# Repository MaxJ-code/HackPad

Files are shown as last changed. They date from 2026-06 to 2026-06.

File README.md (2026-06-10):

# PhotoPad
PhotoPad is a 12 key macropad with a rotary encoder and an OLED Display, designed to be the best helping hand possible for photography and every other daily-life computer based task.

It's supposed to help speeding up the Lightroom Classic workflow, aswell as basic navigation.
The firmware isn't final, because I don't know the keylayout that fits me best, yet.

# Design
MacropadDesign

# Schematic
Schematic

# PCB
PCB

# Case
It features two separate parts with a support for the screen, the cutout for the USB-C and standoffs for the PCB.

Case_sideview
Case_backview

# Firmware
The firmware is KMK based and easy to understand.

# BOM
- 1x Case (2 3D-printed parts)
- 1x XIAO RP2040
- 11x Cherry MX Switches
- 1x EC11 Rotary Encoder
- 1x 0.91" 128x32 OLED Display
- 12x 1N4148 DO-35 Diodes.
- 4x M3x5x4 Heatset inserts
- 4X M3x12mm SHCS Bolts

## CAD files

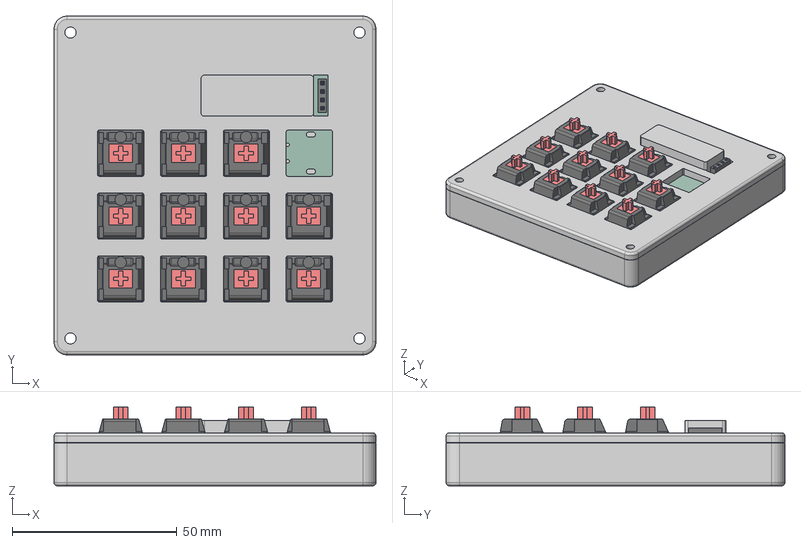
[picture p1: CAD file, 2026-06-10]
CAD/assembled-model.step
97.6 x 102.7 x 23.9 mm
D_DO-35_SOD27_P7.62mm_Horizontal_1 x 12
PinSocket_1x04_P2.54mm_Vertical_1
HackPad_PCB
type-c v2
smd_button v3
DOUT
DIN
VSS
VDD
smd_button v3(Mirror)

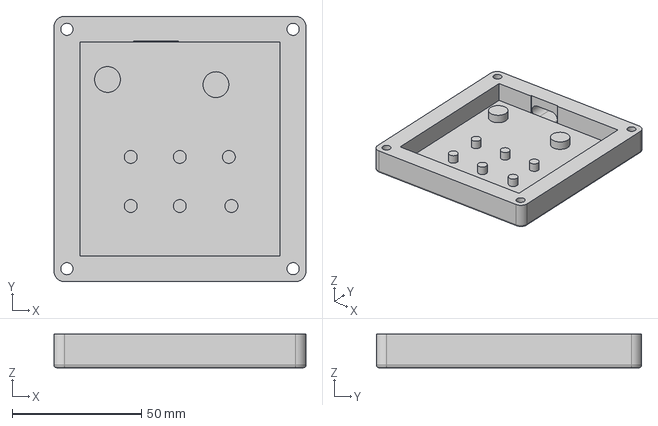
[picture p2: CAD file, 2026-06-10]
production/Bottom.step
97.6 x 102.7 x 13.0 mm

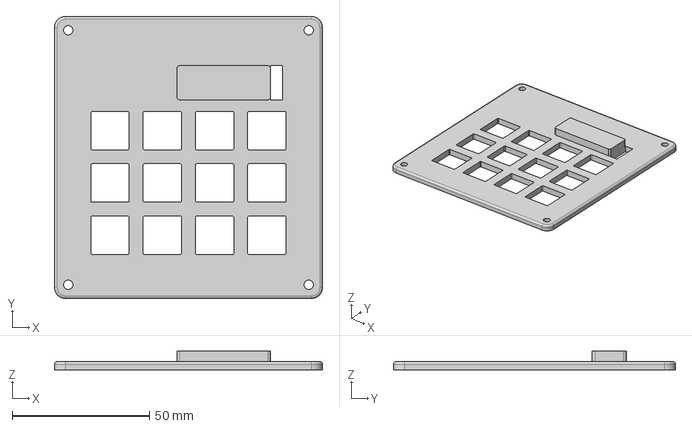
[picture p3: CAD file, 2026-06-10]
production/Top.step
97.6 x 102.7 x 6.77 mm

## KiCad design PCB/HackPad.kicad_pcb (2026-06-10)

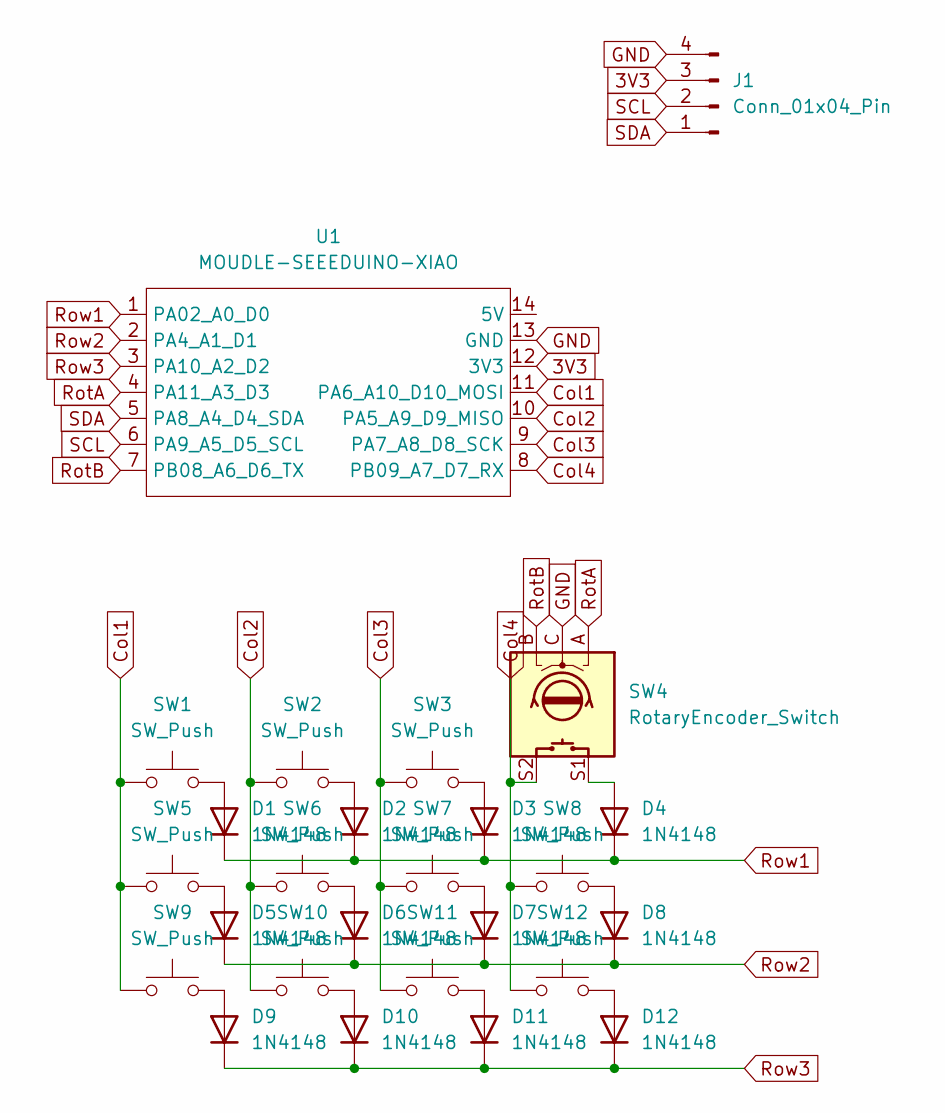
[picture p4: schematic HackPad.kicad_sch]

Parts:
D1, D2, D3, D4, D5, D6, D7, D8, D9, D10, D11, D12: 1N4148; D_DO-35_SOD27_P7.62mm_Horizontal
J1: Conn_01x04_Pin; PinSocket_1x04_P2.54mm_Vertical
SW1, SW2, SW3, SW5, SW6, SW7, SW8, SW9, SW10, SW11, SW12: SW_Push; SW_Cherry_MX_1.00u_PCB
SW4: RotaryEncoder_Switch; RotaryEncoder_Alps_EC11E-Switch_Vertical_H20mm
U1: MOUDLE-SEEEDUINO-XIAO; XIAO-Generic-Hybrid-14P-2.54-21X17.8MM

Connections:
3V3: J1.3, U1.12 (3V3)
Col1: SW1.1, SW5.1, SW9.1, U1.11 (PA6_A10_D10_MOSI)
Col2: SW2.1, SW6.1, SW10.1, U1.10 (PA5_A9_D9_MISO)
Col3: SW3.1, SW7.1, SW11.1, U1.9 (PA7_A8_D8_SCK)
Col4: SW4.S2, SW8.1, SW12.1, U1.8 (PB09_A7_D7_RX)
GND: J1.4, SW4.C, U1.13 (GND)
unnamed: D1.2 (A), SW1.2
unnamed: D2.2 (A), SW2.2
unnamed: D3.2 (A), SW3.2
unnamed: D4.2 (A), SW4.S1
unnamed: D5.2 (A), SW5.2
unnamed: D6.2 (A), SW6.2
unnamed: D7.2 (A), SW7.2
unnamed: D8.2 (A), SW8.2
unnamed: D9.2 (A), SW9.2
unnamed: D10.2 (A), SW10.2
unnamed: D11.2 (A), SW11.2
unnamed: D12.2 (A), SW12.2
RotA: SW4.A, U1.4 (PA11_A3_D3)
RotB: SW4.B, U1.7 (PB08_A6_D6_TX)
Row1: D1.1 (K), D2.1 (K), D3.1 (K), D4.1 (K), U1.1 (PA02_A0_D0)
Row2: D5.1 (K), D6.1 (K), D7.1 (K), D8.1 (K), U1.2 (PA4_A1_D1)
Row3: D9.1 (K), D10.1 (K), D11.1 (K), D12.1 (K), U1.3 (PA10_A2_D2)
SCL: J1.2, U1.6 (PA9_A5_D5_SCL)
SDA: J1.1, U1.5 (PA8_A4_D4_SDA)

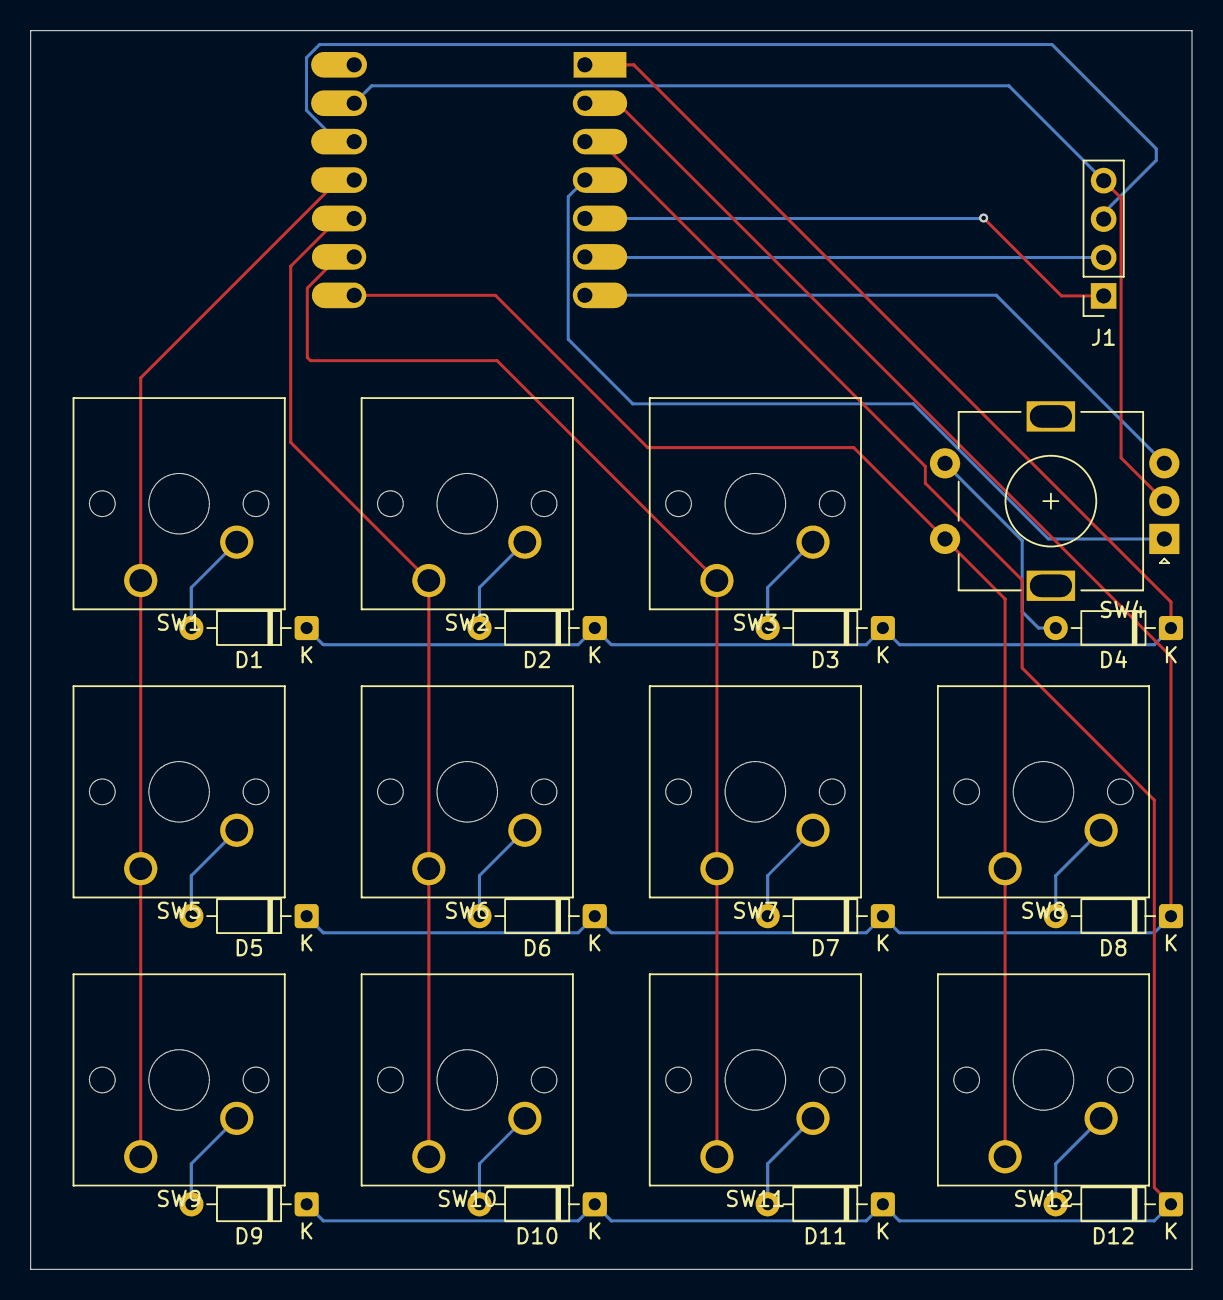
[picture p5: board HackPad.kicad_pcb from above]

Board: 2 copper layers, 76.8 x 81.9 mm, 26 parts (1 on the bottom side), 25 nets.

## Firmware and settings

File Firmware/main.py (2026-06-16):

import board
import busio
from kmk.kmk_keyboard import KMKKeyboard
from kmk.keys import KC
from kmk.scanners import DiodeOrientation
from kmk.modules.encoder import EncoderHandler
from kmk.modules.layers import Layers
from kmk.extensions.media_keys import MediaKeys
from kmk.modules.mouse_keys import MouseKeys
from kmk.extensions.display import Display
from kmk.extensions.display.ssd1306 import SSD1306
from kmk.handlers.sequences import simple_key_sequence


# Pin and Modules Definition
keyboard = KMKKeyboard()
keyboard.col_pins = (board.D10, board.D9, board.D8, board.D7)
keyboard.row_pins = (board.D0, board.D1, board.D2)
keyboard.diode_orientation = DiodeOrientation.COL2ROW
Encoder_handler = EncoderHandler()
Encoder_handler.pins = ((board.D3,board.D6,NONE),)
i2c_bus = busio.I2C(board.D5, board.D4)
driver = SSD1306(i2c=i2c_bus, device_address=0x3C)
display = Display(display_driver=driver, width=128, height=32, flip=False)
keyboard.modules.append(Layers())
keyboard.modules.append(Encoder_handler)
keyboard.modules.append(MediaKeys)
keyboard.modules.append(MouseKeys)
keyboard.extensions.append(display)


#Layer definitions
BASE = 0
NAV_LAYER = 1
LIGHTROOM = 2
LR_SELECT = 3
LR_RATING = 4
DAVINCIRESOLVE = 5
DR_ZOOM = 6

PROGRAMS = [BASE, LIGHTROOM, DAVINCIRESOLVE]


#Button definitions
class MoveProgram(Key):
    def __init__(self, direction):
        super().__init__()
        self.direction = direction
    
    def on_press(self, keyboard, *args, **kwargs):
        global current_prog_idx

        current_prog_idx = (current_prog_idx + self.direction) % len(PROGRAMS)
        next_layer = PROGRAMS[current_prog_idx]
        if keyboard.active_layers:
            keyboard.active_layers[0] = next_layer
        else:
            keyboard.active_layers.append(next_layer)

        return keyboard
    


TRANS = KC.TRNS

#BASE
PREV_TRACK = KC.MPRV
PLAY_PAUSE = KC.MPLY
NEXT_TRACK = KC.MNXT
NAV_BUTTON = KC.MO(NAV_LAYER)
CHROME = KC.F13                     #F-keys need to be set in shortcut settings
EXPLORER = simple_key_sequence(
    (
        KC.LGUI(KC.E)
    )
)
SPOTIFY = KC.F14
DISCORD = KC.F15

#NAVIGATION
PREV_PROG = MoveProgram(-1)
NEXT_PROG = MoveProgram(1)

#LIGHTROOM
SELECT = KC.MO(LR_SELECT)
RATING = KC.MO(LR_RATING)
GRID = KC.G
LOUPE = KC.E
DEVELOP = KC.D
COMPARE = KC.C
PICK = KC.P
UNPICK = KC.U
REJECT = KC.X
CROP = KC.R
MASK = simple_key_sequence(
    (
        KC.LSFT(KC.W)
    )
)


#DAVINCI RESOLVE
ZOOM = KC.MO(DR_ZOOM)
DR_ZOOM_IN = simple_key_sequence(
    (
        KC.LCTRL(KC.EQUAL)
    )
)
DR_ZOOM_OUT = simple_key_sequence(
    (
        KC.LCTRL(KC.MINUS)
    )
)


#Display Layer Map
keyboard.layer_names = ['Normal', 'Lightroom', 'LR-Select']


#Keymap
keyboard.keymap = [
    [#BASE 
     PREV_TRACK,    PLAY_PAUSE,     NEXT_TRACK,     NAV_BUTTON, 
     CHROME,        EXPLORER,       SPOTIFY,        DISCORD,
     ,              ,               ,               ], 
    [#NAV_LAYER
     TRANS,         TRANS,          TRANS,          TRANS, 
     TRANS,         TRANS,          TRANS,          TRANS,
     TRANS,         TRANS,          TRANS,          TRANS],
    [#LIGHTROOM
     GRID,          RATING,         SELECT,         NAV_BUTTON, 
     LOUPE,         PICK,           UNPICK,         REJECT,
     DEVELOP,       COMPARE,        CROP,           MASK],
    [#LR_SELECT
     TRANS,         TRANS,          TRANS,          TRANS, 
     TRANS,         TRANS,          TRANS,          TRANS,
     TRANS,         TRANS,          TRANS,          TRANS],
    [#LR_RATING
     TRANS,         TRANS,          TRANS,          TRANS, 
     KC.N5,         TRANS,          TRANS,          TRANS,
     KC.N1,         KC.N2,          KC.N3,          KC.N4],
    [#DAVINCI RESOLVE
     ,              ,               ZOOM,         NAV_BUTTON, 
     ,              ,               ,               ,
     ,              ,               ,               ],
    [#DR_ZOOM
     TRANS,         TRANS,          TRANS,          TRANS, 
     TRANS,         TRANS,          TRANS,          TRANS,
     TRANS,         TRANS,          TRANS,          TRANS]
]


#Rotary Encoder Map
Encoder_handler.map =   [
                            ((KC.VOLD, KC.VOLU),),
                            ((KC.PREV_PROG, KC.NEXT_PROG),),
                            ((KC.MW_UP, KC.MW_DN),),
                            ((KC.COMMA, KC.DOT),),
                            ((),), 
                            ((),),
                            ((DR_ZOOM_OUT, DR_ZOOM_IN),)
                        ]


#Initialisation
if __name__ == "__main__":
    keyboard.go()

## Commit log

2026-06-10 Revise README for PhotoPad project details
    Updated project name and added detailed descriptions for the PhotoPad, including design, schematic, PCB, case, firmware, and BOM sections.
2026-06-10 Add images to README for case views
    Added images for case side and back views.
2026-06-10 Fix duplicate BOM entries in README
    Removed duplicate BOM entries in the README.
